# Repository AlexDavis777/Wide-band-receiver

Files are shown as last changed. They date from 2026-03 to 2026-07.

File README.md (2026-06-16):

# Wide band receiver
An all mode wide band receiver project, covering 0.1-860MHz. Using Arduino IDE for firmware, SI4732 as demodulator, AD831 as active mixer and an I2C "tin can" TV tuner for VHF/UHF reception.
A tinySA can be added and will then get synchronized by the receiver via serial connection.      
 
This is an experimental receiver and should not be considered as a flawless building description with guaranteed success. 
It does require RF experience and tools.

It uses single conversion for frequencies below 50MHz and double conversion above. A crystal filter in front of the SI4732 and a SI5351 as local oscillator improve filtering and eliminate chuffing noises. 

A NOS I2C tv tuner covers 50-860MHz. A "shortwave only" version (without tuner) can be compiled.
The driver module "TVTuner.ino" is designed for Philips PAL I2C tuners and has been tested on UR1316-3 and CD1316-3 tuners. UV1316-3 tuner should also work.
These tuners are currently available on the internet from several sources. Tuner AGC voltage gets generated by one of the ESP32 DAC's.   
Other Philips I2C tuners may have a different pinout and different IF and AGC specs, but should work as long as they use the same data format (4 byte Philips telegram).

It may be possible to adapt it for other brands by adjusting the data packet that gets sent to the tuner. 
Philips tuners work fine with +3.3V on the I2C bus. Other brands may need level shifters. NTSC tuners use a different IF and would also require to adapt the LO frequency accordingly.

ESP32, ILI9488 with an RESISTIVE touch display (the red pcb), SI4732, SI5351 and AD831 are the main components. No other displays are supported.
Volume, squelch and fine tune get directly controlled via potentiometers.
Different options like a TCXO version or a hardware narrow band FM demodulator are available.

It does include some nice features, such as remote control over WiFi, digital audio processor, morse decoder, slow scan waterfall, memory bank scanning, station lists, .wav recorder, WIFI file transfer and more.
To build the hardware you should have experience with RF circuits and the appropiate toolset. At least a tinySA and NanoVNA are strongly recommended. 

See the main file SI4732Radio_V0_611.ino for more details.


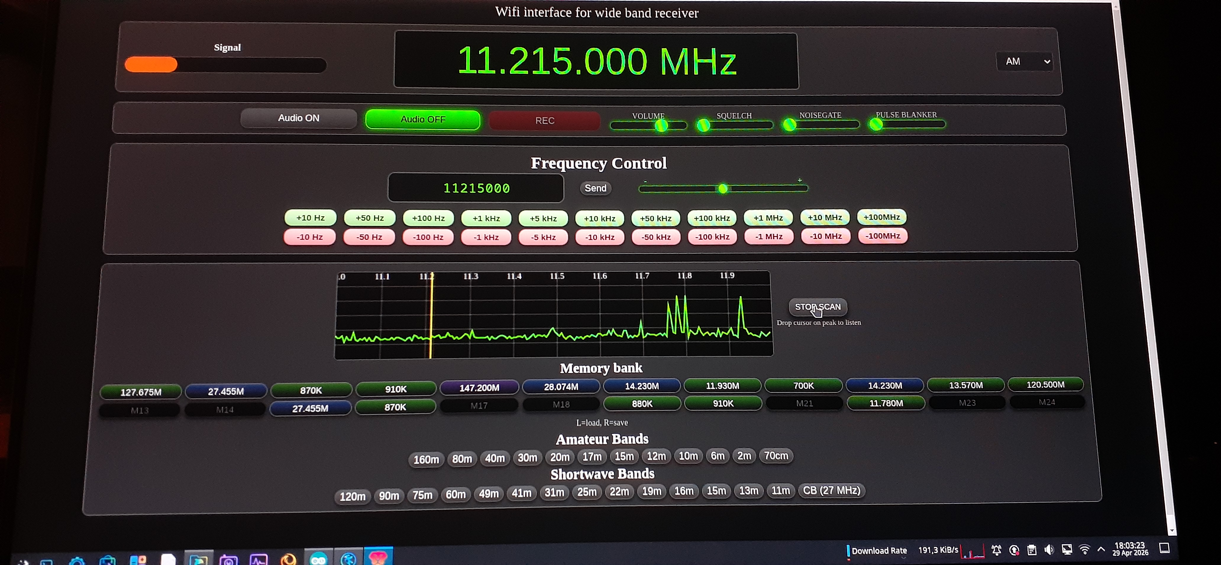
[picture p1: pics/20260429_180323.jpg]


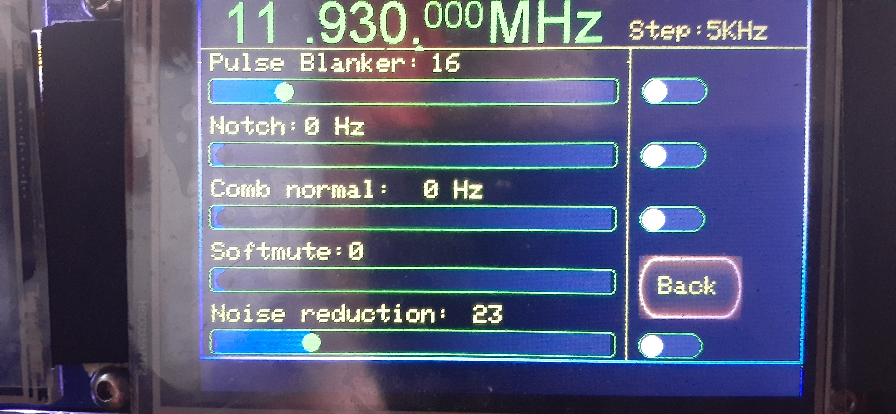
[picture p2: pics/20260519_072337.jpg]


.

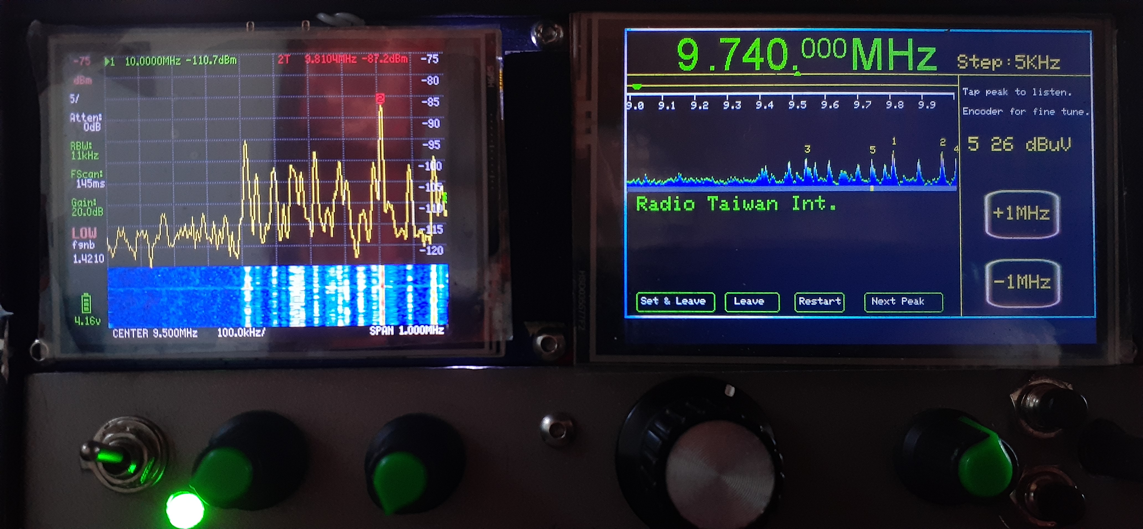
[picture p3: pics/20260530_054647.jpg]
.

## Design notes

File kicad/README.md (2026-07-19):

# Wide band receiver
Added prototype PCBs. Open Source Hardware. Please feel free to use or adapt and improve as you see fit for your project.

Front Bezel and MCU/Display PCB boards work well.
Radio PCB Board works well but is in need of further testing and possible layout optimization.

Rev2 Radio board includes support MAR6-SM on same footprint as SBB5089 and for using ADE-1+ mixer
alternative instead of AD831.
The ADE-1+ mixer does away with a need for the 9 volt regulator and enables powering the radio from 7.4 volts, thus
halving current consumption and reduces regulator heat, making the device more portable.

<p align="center">
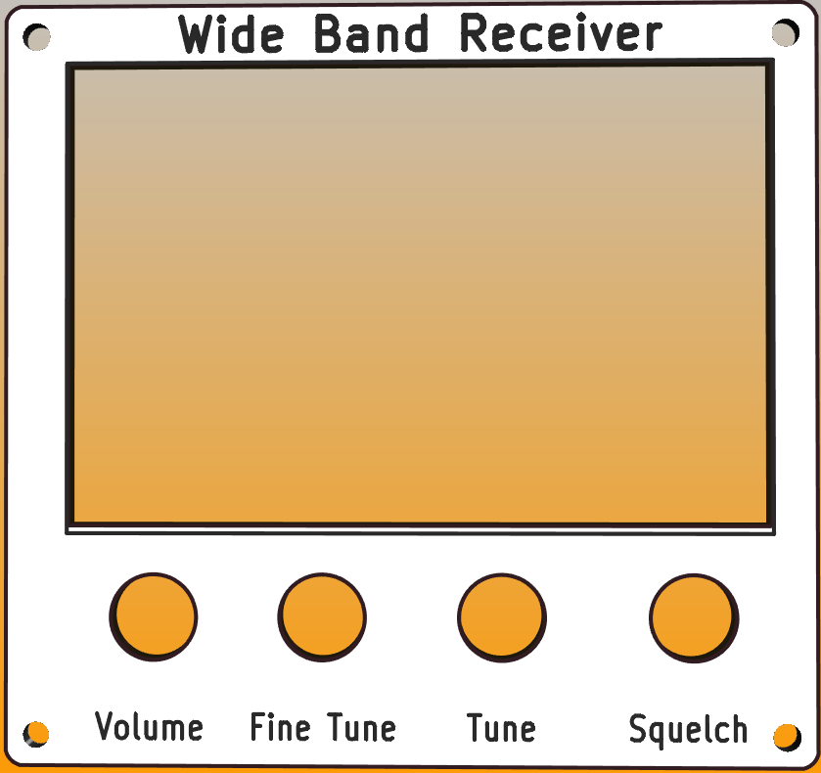
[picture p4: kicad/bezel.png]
    

<p align="center">
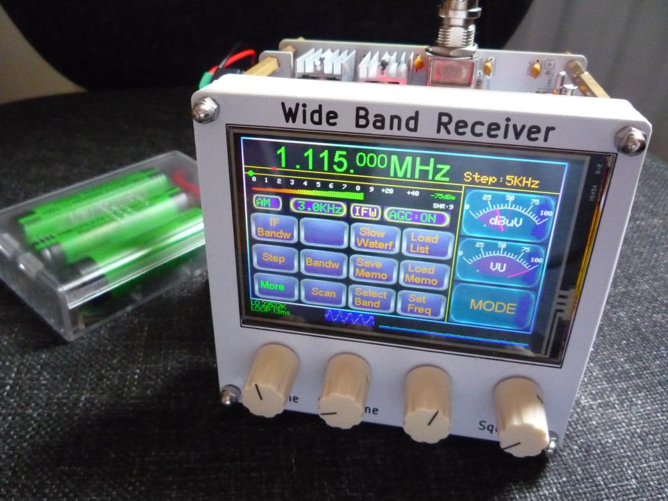
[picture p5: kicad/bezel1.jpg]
    

<p align="center">
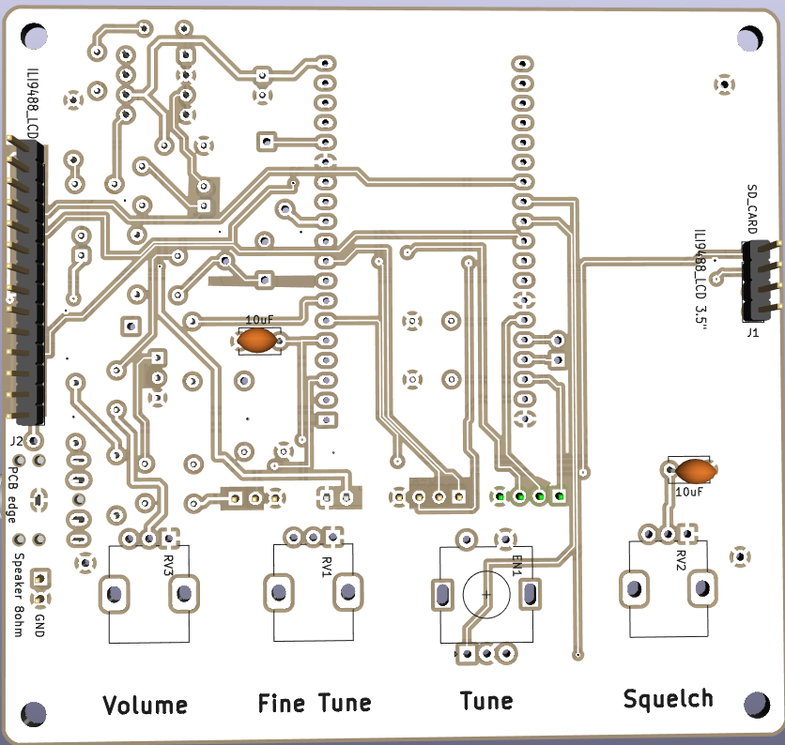
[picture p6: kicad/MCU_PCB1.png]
    

<p align="center">
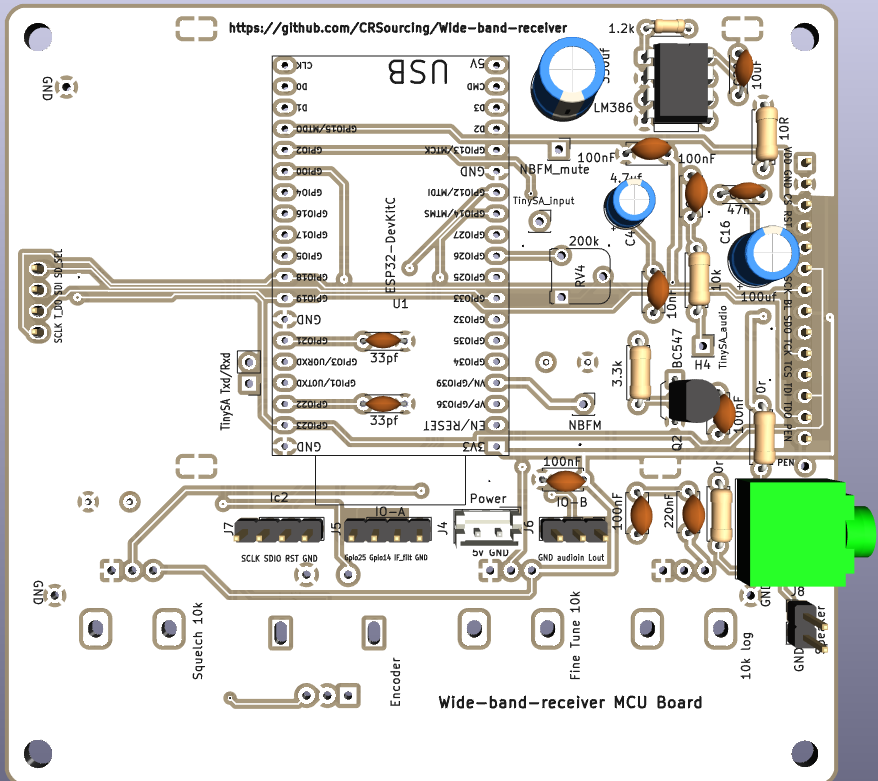
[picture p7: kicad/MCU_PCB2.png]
    

<p align="center">
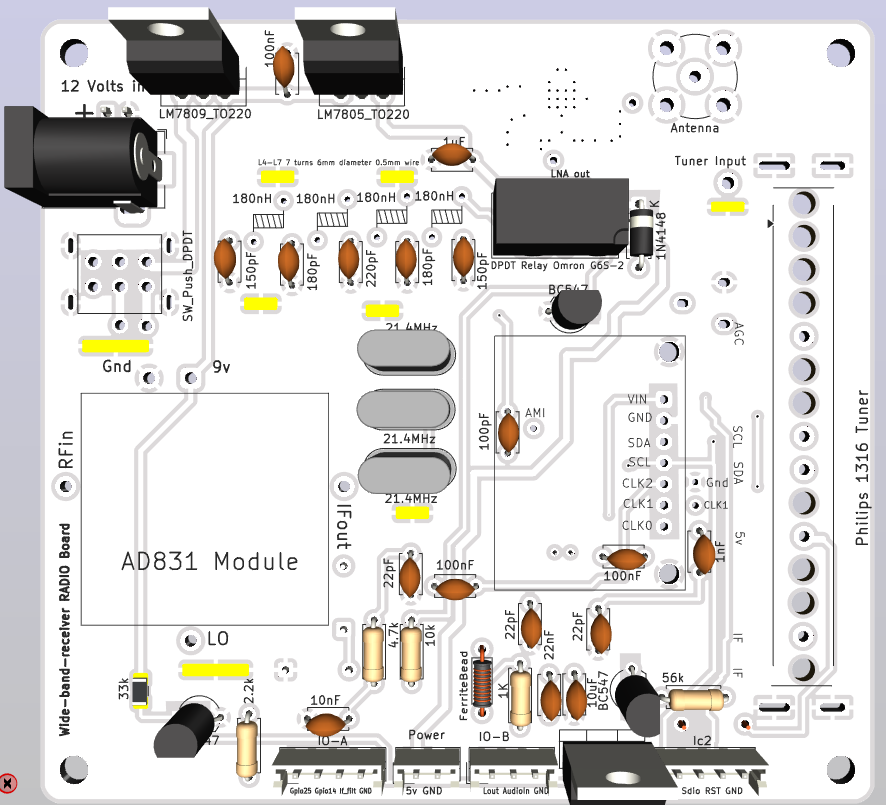
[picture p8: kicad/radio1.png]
    

<p align="center">
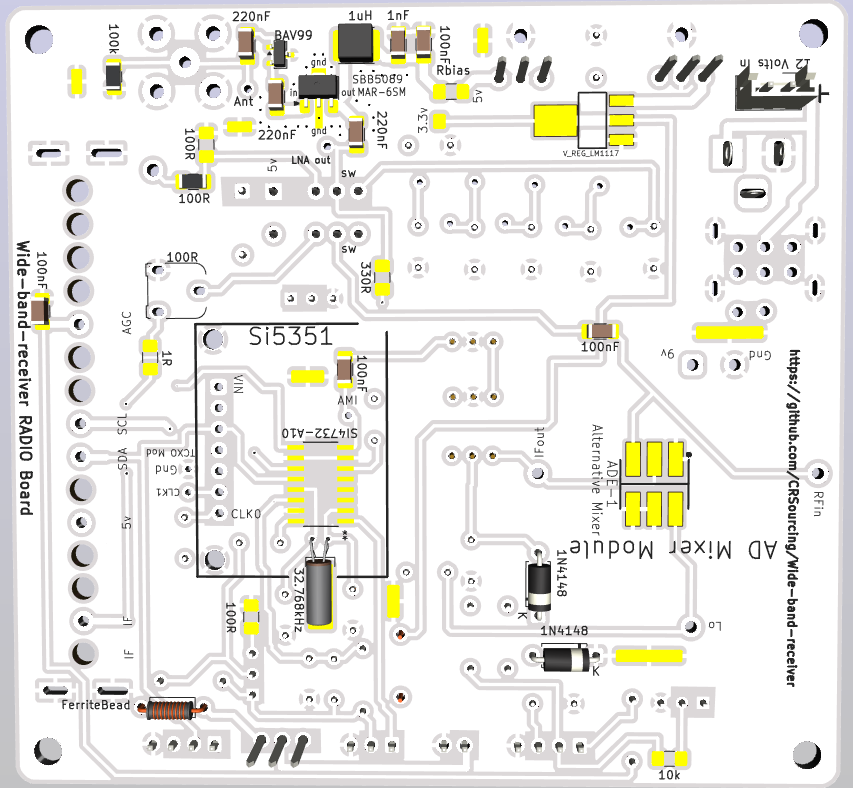
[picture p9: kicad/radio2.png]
    

<p align="center">
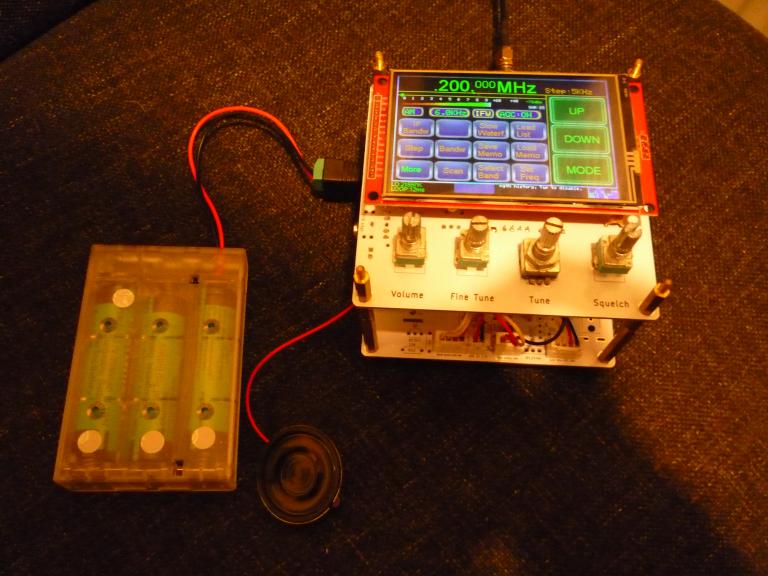
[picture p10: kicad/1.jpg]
    

<p align="center">
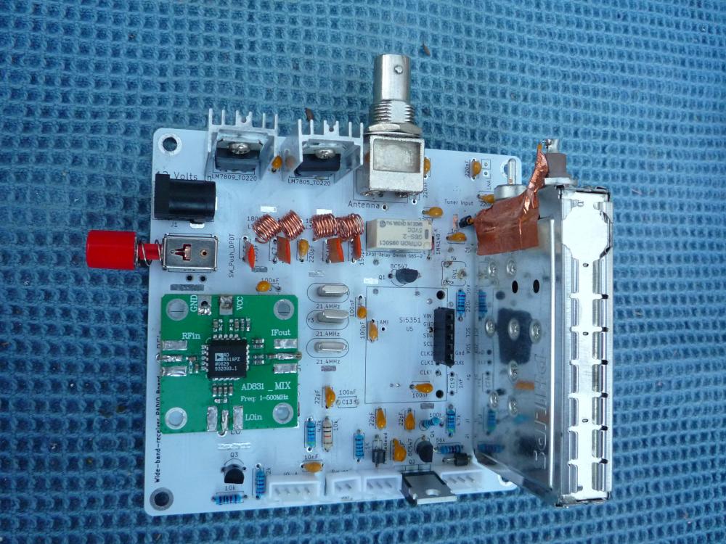
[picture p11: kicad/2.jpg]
    

<p align="center">
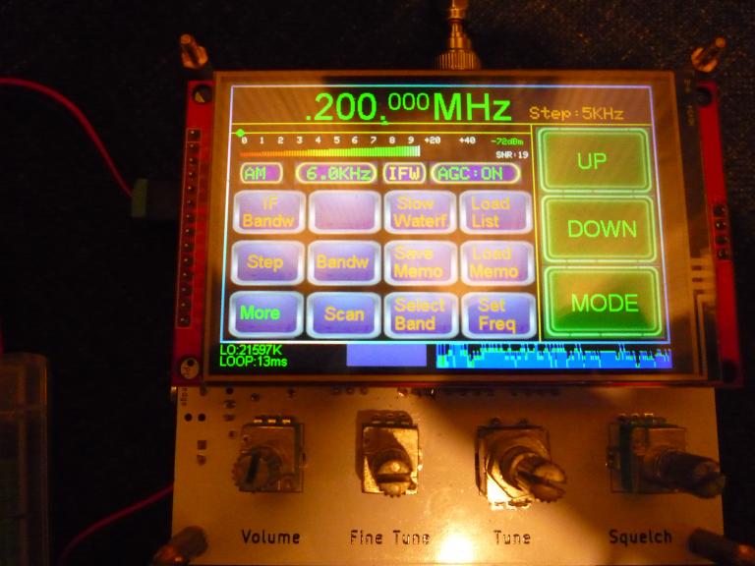
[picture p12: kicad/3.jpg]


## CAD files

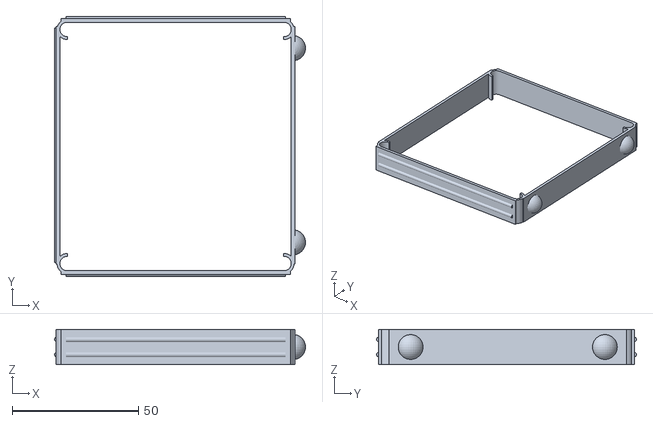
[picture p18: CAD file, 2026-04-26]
3dPrints/Top1.stl
99.5 x 103.0 x 14.0

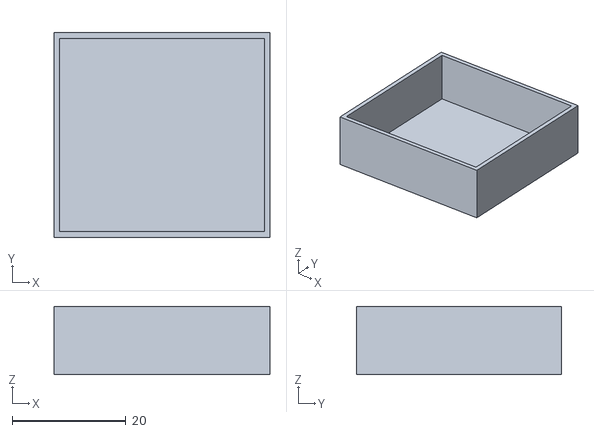
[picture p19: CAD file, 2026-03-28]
3dPrints/screenBox_mixer.stl
38.0 x 36.0 x 12.0

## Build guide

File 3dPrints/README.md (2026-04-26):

# Wide band receiver
3D printed parts added here.

<p align="center">
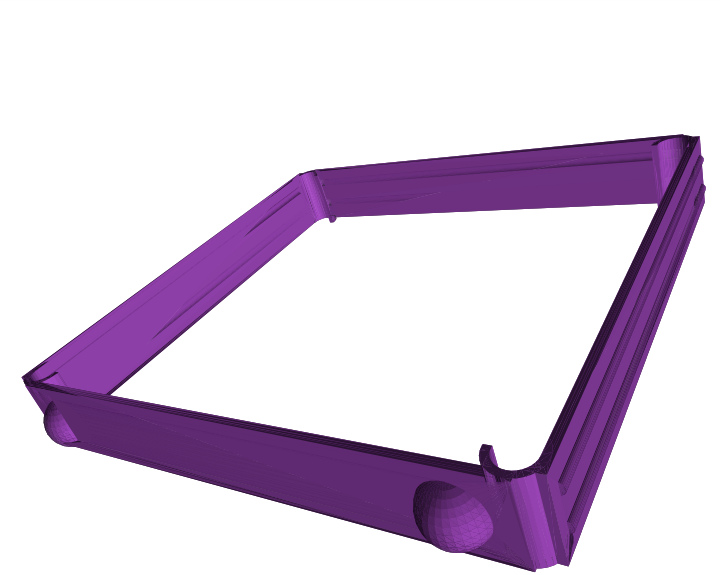
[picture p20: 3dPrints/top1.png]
    

<p align="center">
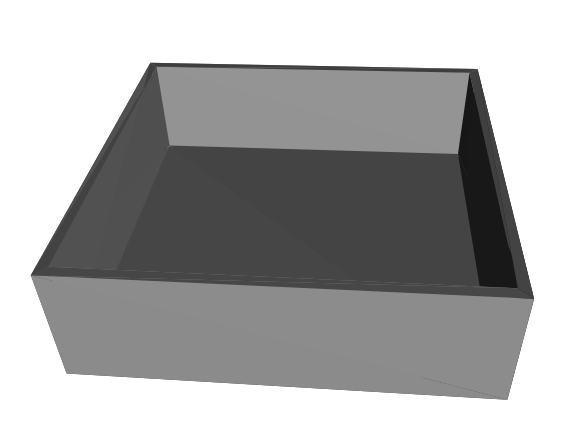
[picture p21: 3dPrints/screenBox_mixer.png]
    

<p align="center">
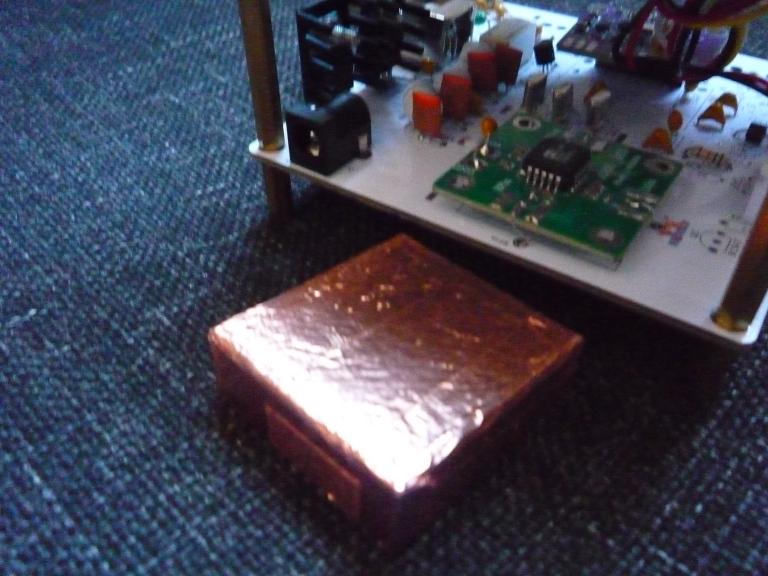
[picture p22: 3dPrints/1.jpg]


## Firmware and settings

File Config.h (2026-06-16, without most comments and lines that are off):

#include <sys/_stdint.h>
#define CONFIG_H
#ifdef TV_TUNER_PRESENT
#define LOW_BAND_LOWER_LIMIT 50000000  // TV tuner bands limits tested with tuner UR1316
#define LOW_BAND_UPPER_LIMIT 167000000
#define MID_BAND_UPPER_LIMIT 454000000
#define HIGH_BAND_UPPER_LIMIT 875000000      // sensitivity decreases rapidly > 850MHz
#define SHORTWAVE_MODE_UPPER_LIMIT 50000000  //above 50MHz tuner is in use
#define HIGHEST_ALLOWED_FREQUENCY HIGH_BAND_UPPER_LIMIT
#else
#define HIGHEST_ALLOWED_FREQUENCY 50000000  // 50MHz
#define SHORTWAVE_MODE_UPPER_LIMIT 50000000
#endif
#define LOWEST_ALLOWED_FREQUENCY 100000  // could go lower, but noise gets dominant
#define TFT_BLACK 0x0000
#define TFT_NAVY 0x000F
#define TFT_DARKDARKGREEN 0x1b41
#define TFT_DARKGREEN 0x03E0
#define TFT_MIDGREEN 0x0584
#define TFT_DARKCYAN 0x03EF
#define TFT_DARKVIOLET 0x2028  // 4,1,8
#define TFT_MAROON 0x7800
#define TFT_PURPLE 0x780F
#define TFT_OLIVE 0x7BE0
#define TFT_LIGHTGREY 0xD69A
#define TFT_DARKGREY 0x7BEF
#define TFT_DARKDARKGREY 0x2945
#define TFT_SILVERBLUE 0x8D5F
#define TFT_BLUE 0x001F
#define TFT_GREEN 0x07E0
#define TFT_CYAN 0x07FF
#define TFT_RED 0xF800
#define TFT_DARKRED 0x90C1
#define TFT_MAGENTA 0xF81F
#define TFT_YELLOW 0xFFE0
#define TFT_WHITE 0xFFFF
#define TFT_ORANGE 0xFDA0
#define TFT_DEEPORANGE 0xf401
#define TFT_GREENYELLOW 0xB7E0
#define TFT_PINK 0xFE19
#define TFT_DARKBROWN 0x6a44
#define TFT_BROWN 0x9A60
#define TFT_LIGHTBROWN 0x9347
#define TFT_GOLD 0xFEA0
#define TFT_SILVER 0xC618
#define TFT_SKYBLUE 0x867D
#define TFT_VIOLET 0x915C
#define TFT_GREY 0x5AEB
#define TFT_FOREGROUND TFT_GOLD
#define TFT_GRID TFT_YELLOW
#define TFT_LIGHTBULB 0xFFDC
#define TFT_BTNBDR TFT_NAVY
#define TFT_BTNCTR TFT_BLUE
#define TFT_MAINBTN_BDR TFT_NAVY
#define TFT_MAINBTN_CTR TFT_GREY
#define TFT_DIAL_BACKGROUND TFT_BLACK
#define TFT_DIAL_TICKS TFT_LIGHTBULB
#define TILE_WIDTH 75
#define TILE_HEIGHT 50
#define SPRITEBTN_WIDTH 80
#define SPRITEBTN_HEIGHT 50
#define M_SIZE 0.59  // meter size, does not affect the sprite frame size
#define DISP_WIDTH 480
#define DISP_HEIGHT 320
#define AM 1
#define LSB 2
#define USB 3
#define NBFM 4
#define WBFM 5
#define SYNC 6  //AM Sync, doesn't work well
#define CW 7
#define FMSTARTFREQ 10000  // WBFM initial freq, use frequency of a nice radio station
#define DEFAULT_AM_STEP 5000
#define DEFAULT_SSB_STEP 1000
#define DEFAULT_CW_STEP 100
#define DEFAULT_SYNC_STEP 5000
#define DEFAULT_NBFM_STEP 12500
#define DEFAULT_WBFM_STEP 100000
#define IF_FILTER_BANDWIDTH_PIN 0  // switches filter bandwidth, GPIO 0 okay for this
#define RESET_PIN 12               // SI4735 reset
#define NBFM_MUTE_PIN 13           // Hardware NBFM demodulator mute pin, muted when another modType is in use
#define RELAY_SWITCH_OUTPUT 14     // activates IF  and LNA relays. Low = tvTuner connected to LNA and AD831
#define ENCODER_PIN_B 16           // Encoder left and right pins
#define ENCODER_PIN_A 17           // Encoder left and right pins
#define ESP32__SDA 21           //  bus
#define ESP32__SCL 22           //  bus
#define TUNER_AGC_PIN 25           // tuner AGC pin
#ifdef NBFM_DEMODULATOR_PRESENT
#define TUNING_VOLTAGE_READ_PIN 27  // Tuning voltage read pin
#endif
#define ENCODER_BUTTON 33   // encoder pressbutton pin
#define MUTEPIN 32          // goes via 3.3K to base of external mute transistor
#define FINETUNE_PIN 34     // finetune pot center pin
#define SQUELCH_POT 35      // squelch pot center pin
#define AUDIO_INPUT_PIN 36  // audio input for FFT analysis from SI4732
#define PULSE_PIN 39        // squarewave audio input
#define WATERFALL_SCREEN_WIDTH 480
#define WATERFALL_SCREEN_HEIGHT 220
#define FRAMEBUFFER_240 240
#define FRAMEBUFFER_HEIGHT 220
#define AUDIO_FRAMEBUFFER_HEIGHT 40
#define TIME_UNTIL_ANIMATIONS 60  // seconds until animations start (pacm, audio waterfall)
#define TFT_SCK 18
#define TFT_MOSI 23
#define TFT_MISO 19
#define TFT_RESET 4
#define FORMAT_LittleFS_IF_FAILED true  //format the LittleFS if not already formatted or error
#define SCK 18    // definitions for SD card
#define MISO 19   //MISO=SDO
#define MOSI 23   //MOSI=SDI
#define SD_CS 33  // Connect CS to GPIO33 (also used for encoder press button), all other connections in parallel to SPI bus.
#define SAMPLES 256
#define FFT_SPEED_OVER_PRECISION
#define FFT_SQRT_APPROXIMATION
#define DEFAULT_SPAN 1000000  // cover 1MHz
#define FREQ_TO_MHZ FREQ / 1000000 * 1000000
#define FREQ_TO_KHZ FREQ / 1000
#define WINDOW_CENTER_FREQ (FREQ / 1000000 * 1000000) + (DEFAULT_SPAN / 2)
#define SHOW_SPLASHSCREEN
Rotary encoder = Rotary(ENCODER_PIN_A, ENCODER_PIN_B);
TFT_eSPI tft = TFT_eSPI();
TFT_eSPI_ext etft = TFT_eSPI_ext(&tft);  // Install from https://github.com/FrankBoesing/TFT_eSPI_ext // Fonts avail. in the following sizes:
TFT_eSprite spr1 = TFT_eSprite(&tft);  // miniwindow, bottom center of screen
TFT_eSprite spr2 = TFT_eSprite(&tft);  // rolling RSSI indicator
TFT_eSprite spr3 = TFT_eSprite(&tft);  // audio waterfall after user inactivity
Si5351 si5351(0x60);  //Si5351  Address 0x60
SI4735 si4735;
Preferences preferences;  // Flash save data
PNG png;
File myfile;
SdFat sd;  // SdFat library
FsFile f;
SPIClass spiSD = SPIClass(VSPI);                // for SDcard
DacESP32 dac2(GPIO_NUM_26), dac1(GPIO_NUM_25);  // dac2 for sine wave oscillator, dac1 for tuner AGC or SW RF attenuator
float RvReal[SAMPLES * 2];
float RvImag[SAMPLES * 2];
ArduinoFFT<float> FFT = ArduinoFFT<float>(RvReal, RvImag, 512, 8000);  // 4KHz max, 255 usable bins
RingBuffer logBuffer;                                                  // debug logs
WebServer server(80);                // LittleFS uploader
AsyncWebServer aserver(HTTTP_PORT);  // WiFi interface
AsyncWebSocket ws("/ws");            // websocket
const uint16_t size_content = sizeof ssb_patch_content;  // see ssb_patch_content in patch_full.h or patch_init.h
volatile bool clw = false;                               // encoder direction clockwise
volatile bool cclw = false;                              // counter clockwise
const char ver[] = "V.611";  // version
long I2C_BUSSPEED = 500000;  // Adjust as needed.
long STEP;                    //STEP size
long OLDSTEP;
const long MIN_FREQ = 100000;          // lowest frequency
long SI5351calib = 0;                  //  si5351.set_correction
long fineTuneOffset = 0;               // used when fine tune offset will not get displayed
long passbandShift = 0;                // shift SI4732 frequency through filter passband
const long tunerIFLowEnd = 37000000l;  // Defines the 1 MHz segment of the tuner IF spectrum which will be used. This constant determines the low end of the segment.
long FREQ = 100000;            // receiver tuned frequency
long FREQ_OLD = -1;            // start with != FREQ value
long F_OLD = -1;               // value holder for displayLOFreq()
long LO_RX;                    // SI5351 frequency in Hz
int SI4735TUNED_FREQ = 21400;  // 1st IF in KHz Also mid frequency of crystal filter, SI4732 needs to be tuned to it.
bool wideIFFilter = true;  // IF filter bandwidth false = narrow, true = wide;
bool afcEnable = false;
int NBFMOffset = 0;              // shift of  SI4735TUNED_FREQ in KHz to demodulate FM on the flank of the filter.
int afcVoltage = 410;            // voltage tap from the quadrature demodulator
int discriminatorZero;           // middle of the tuning meter needle
uint8_t tuningMeterDivider = 5;  // adjust so that the tuning meter shows deviation in KHz correctly
uint8_t triggerUpdate = 0;       // triggers AGC updates (Attn buttons)
int8_t SWGainCorrection = 10;    //  corrects shortwave S Meter
uint16_t SWAttn = 0;             // Shortwave attenuator attenuation, 0 = 0dB, 255= 30dB attenuation
uint8_t SWMinAttn = 0;           // Shortwave attenuator minimum attenuation, 0 = 0dB, 255= 30dB attenuation
long lastAMFREQ = -1;            // AM frequency before switching to WBFM
long span = 1000000;             // tinySA default span, configured in TSA Presets 0 and 1
long potVal;                     // fine tune potentiometer read value
long lim2 = 0;                   // frequency limits from touchpad entries
long lim1 = 0;                   // frequency limits from touchpad entries
long keyVal = 0;                 // scan mode frequencies delivered from touchpad
bool TVTunerActive = false;     //will get set to true when tuner in use
bool lowSideInjection = false;  // for debugging, this will change injection mode
uint8_t gainLimit = 180;        // adjust tuner gain when no signal received, depending on gain of the LNA. Must be as low as possible to reduce cross modulation
uint8_t agcVal = gainLimit;     // starting point of the AGC
uint32_t OLDPLLFREQ = -1;
uint32_t PLLFREQ = 0;              // PLL freq of the TV tuner
int16_t tunerOffsetPPM = 0;        // corrects tuner crystal offset
int8_t tunerGainCorrection = -10;  // corrects sMeter and dBm values when tuner is in use
#ifdef TV_TUNER_PRESENT
long MAX_FREQ = HIGHEST_ALLOWED_FREQUENCY;
#endif
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

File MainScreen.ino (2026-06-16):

void mainScreen() {  // main screen does not block loop(), all other screens do

  if (redrawMainScreen) {  // redraw main screen when coming from a function that overwrites it
    resetSmeter = true;
    F_OLD = -1;  // re trigger LO display
    drawBigBtns();
    drawMainButtons();
    DrawSmeterScale();
    printModulation();
    printBandWidth();
    showIFBandwidth();
    printAGC();
    readSquelchPot(true);  // read and draw position
    redrawMainScreen = false;
  }
  readMainBtns();
}


//##########################################################################################################################//
void redrawIndicators() {

  tft.fillRect(3, 52, 336, 30, TFT_BLACK);  // overwrite area for spectrum
  tft.fillRect(3, 82, 336, 41, TFT_BLACK);  // overwrite area for waterfall
  F_OLD = -1;                               // re trigger LO display
  DrawSmeterScale();
  printModulation();
  printBandWidth();
  showIFBandwidth();
  printAGC();
  redrawMainScreen = true;  // this forces readSquelchPot() to redraw the squelch line and circle
  readSquelchPot(true);
  redrawMainScreen = false;
}


//##########################################################################################################################//

void drawMainButtons() {

  // Background
  if (!altStyle)
    tft.fillRect(2, 56, 337, 233, TFT_BLACK);
  else
    drawButton(2, 56, 337, 233, TFT_NAVY, TFT_DARKGREY);

  draw12Buttons(TFT_BTNCTR, TFT_BTNBDR);

  struct Button {
    const int x;
    const int y;
    const char *label;
  };

  const Button buttons[] PROGMEM = {
    { 275, 245, "Set" }, { 185, 245, "Select" }, { 110, 255, "Scan" }, { 100, 198, "Bandw" }, { 25, 198, "Step" }, { 185, 188, "Save" }, { 270, 188, "Load" }, { 188, 132, "Slow" }, { 270, 132, "Load" }, { 185, 265, "Band" }, { 275, 265, "Freq" }, { 185, 208, "Memo" }, { 267, 208, "Memo" }, { 185, 152, "Waterf." }, { 270, 152, "List" }
  };

  etft.setTTFFont(Arial_14);
  for (int i = 0; i < sizeof(buttons) / sizeof(buttons[0]); i++) {
    etft.setCursor(buttons[i].x, buttons[i].y);
    etft.setTextColor(textColor);
    if (i == 2 && scanMode)
      etft.setTextColor(TFT_SKYBLUE);
    etft.print(buttons[i].label);
  }

  // "More" button
  drawButton(8, 234, TILE_WIDTH, TILE_HEIGHT, TFT_MIDGREEN, TFT_DARKGREEN);
  etft.setTextColor(TFT_GREEN);
  etft.setCursor(20, 254);
  etft.print(F("More"));
  etft.setTextColor(textColor);

#ifdef TINYSA_PRESENT
  etft.setCursor(15, 132);
  etft.print(F("TinySA"));
  etft.setCursor(14, 152);
  etft.print(F("Config"));

#else
  etft.setCursor(40, 132);
  etft.print(F("IF"));
  etft.setCursor(18, 152);
  etft.print(F("Bandw"));
#endif

#ifdef TV_TUNER_PRESENT
  etft.setCursor(100, 132);
  if (TVTunerActive) {
    etft.setTextColor(TFT_SKYBLUE);
    etft.print(F("Tun."));
    etft.setCursor(100, 152);
    etft.print(F("Attn."));
  }
#endif

  if (!TVTunerActive) {
#ifdef SW_ATTENUATOR_PRESENT
    etft.setTextColor(TFT_GREEN);
    etft.print(F("SW"));
    etft.setCursor(100, 152);
    etft.print(F("Attn."));
    etft.setTextColor(textColor);
#endif
  }
}


//##########################################################################################################################//

void readMainBtns() {



  if (!pressed)
    return;



  int buttonID = getButtonID();
  if (!buttonID)
    return;  // outside of area


  redrawMainScreen = true;
  tft.fillRect(135, 295, 92, 25, TFT_BLACK);  // overwrite frozen spectrum window
  switch (buttonID) {
    case 21:
#ifdef TINYSA_PRESENT
      tinySAScreen();
#else
      wideIFFilter = !wideIFFilter;
      setIFBandwidth();
      showIFBandwidth();
#endif
      tRel();
      return;
    case 22:
      hideBigBtns();
#ifdef TV_TUNER_PRESENT
      if (TVTunerActive)
        setInitialTunerGain();
#endif

#ifdef SW_ATTENUATOR_PRESENT
      if (!TVTunerActive)
        setRFAttenuatorMinAttn();
#endif

      break;
    case 23:
      selectWaterFall();
      tRel();
      break;
    case 24:
      picoMenu();
      rebuildMainScreen(false);
      FREQ_OLD = -1;  // trigger update
      return;
    case 31:
      hideBigBtns();
      setSTEP();  // use touchbuttons
      break;
    case 32:
      hideBigBtns();
      setBandwidth(0);  // use touchbuttons
      tRel();
      break;
    case 33:
      hideBigBtns();
      showMemo(false, 1);
      writeMemo();
      tRel();
      break;
    case 34:
      hideBigBtns();
      showMemo(true, 1);
      readMemo();
      tft.fillRect(0, 294, 374, 25, TFT_BLACK);  // overwrite remanents of station names
      displayDebugInfo = true;                   // restore debug info
      tRel();
      break;
    case 41:
      FREQ_OLD = -1;  // re trigger LO display
      hideBigBtns();
      SecScreen();
      tRel();
      break;
    case 42:
      ScanMode();
      tRel();
      tx = ty = pressed = 0;
      break;
    case 43:
      hideBigBtns();
      setBand(false);  // Select Band
      tRel();
      break;
    case 44:
      hideBigBtns();
      freqScreen();
      break;
    default:
      tx = ty = pressed = 0;
      tRel();
      return;
  }
}



//##########################################################################################################################//

void setBandwidth(int mode) {  // mode 0 = bandwidth selected from menu. mode -1 and 1 are called  by touching the indicator areas
  const int TEXT_Y = 195;
  const int positions[] = { 24, 106, 191, 272 };

  const uint8_t usbLsbBandWidths[] = { 0, 1, 2, 3 };
  const uint8_t amBandWidths[] = { 3, 2, 1, 0 };
  const uint8_t cwBandWidths[] = { 4, 5, 3, 3 };

  const char *amBandwidth[] = { "2KHz", "3KHz", "4KHz", "6KHz" };
  const char *ssbBandwidth[] = { "1.2KHz", "2.2KHz", "3KHz", "4KHz" };
  const char *cwBandwidth[] = { "0.5KHz", "1.0KHz", "", "" };
  const char **bandwidth = nullptr;



  if (modType == WBFM)
    return;


  if (mode == 0) {
    for (int j = 0; j < 4; j++) {
      drawButton(8 + j * 83, 235, TILE_WIDTH, TILE_HEIGHT, TFT_BTNCTR, TFT_BTNBDR);
      drawButton(8 + j * 83, 178, TILE_WIDTH, TILE_HEIGHT, TFT_BTNCTR, TFT_BTNBDR);
    }

    tft.fillRect(3, 119, 334, 58, TFT_BLACK);  // overwrite highest row

    etft.setTTFFont(Arial_14);
    etft.setTextColor(TFT_GREEN);

    if (modType == AM)
      bandwidth = amBandwidth;
    else if (modType == USB || modType == LSB || modType == SYNC)
      bandwidth = ssbBandwidth;
    else if (modType == CW)
      bandwidth = cwBandwidth;


    if (bandwidth != nullptr) {
      for (int i = 0; i < 4; ++i) {

        if (modType == AM)
          etft.setCursor(positions[i], TEXT_Y);
        if (modType == LSB || modType == USB || modType == SYNC || modType == CW)
          etft.setCursor(positions[i] - 10, TEXT_Y);  // text is wider

        etft.print(bandwidth[i]);
      }
      etft.setTextColor(textColor);  // Reset to default text color
    }


    tDoublePress();

    delay(10);
    getButtonID();

    if (row == 3) {

      if (modType == USB || modType == LSB || modType == SYNC) {
        bandWidth = usbLsbBandWidths[column - 1];
        lastSSBBandwidth = bandWidth;
      } else if (modType == AM) {
        bandWidth = amBandWidths[column - 1];
        lastAMBandwidth = bandWidth;
      } else if (modType == CW) {
        bandWidth = cwBandWidths[column - 1];
        lastSSBBandwidth = bandWidth;
      }
    }

  }  // endif mode == 0


  else {  // mode -1 and mode 1 are used when touching the indicator area on the left or right

    const uint8_t *bandWidths;
    int maxIndex = 3;
    int i = 0;
    bool isIncrement = (mode == 1);

    if (modType == AM) {
      bandWidths = amBandWidths;
    } else if (modType == USB || modType == LSB || modType == SYNC) {
      bandWidths = usbLsbBandWidths;
    } else if (modType == CW) {
      bandWidths = cwBandWidths;
      maxIndex = 1;
    } else {
      return;
    }

    // find index
    while (i < maxIndex && bandWidths[i] != bandWidth) {
      i++;
    }

    // modify index
    if (isIncrement && i < maxIndex) {
      i++;
    } else if (!isIncrement && i > 0) {
      i--;
    }

    // update bandwidth
    bandWidth = bandWidths[i];
  }
  // set bandwidth
  if (modType == LSB || modType == USB || modType == SYNC || modType == CW) {
    si4735.setSSBAudioBandwidth(bandWidth);
    if (bandWidth <= 2) {
      si4735.setSBBSidebandCutoffFilter(0);
    } else {
      si4735.setSBBSidebandCutoffFilter(1);
    }
  }

  if (modType == AM) {
    si4735.setBandwidth(bandWidth, 1);
  }
  printBandWidth();
}

//##########################################################################################################################//

void printBandWidth() {

  if (altStyle)
    tft.fillRoundRect(75, 95, 92, 22, 10, TFT_BLUE);

  else {
    tft.pushImage(75, 92, 92, 26, (uint16_t *)Oval92);
  }

  tft.setTextColor(TFT_GREEN);
  tft.setCursor(77, 98);

  switch (modType) {
    case WBFM:
      tft.print(F(" 300KHz"));
      break;
    case NBFM:
      tft.print(F(" 10KHz"));
      break;
    case CW:
      if (bandWidth == 4)
        tft.print(F(" 0.5KHz"));
      if (bandWidth == 5)
        tft.print(F(" 1.0KHz"));
      break;
    case USB:
    case LSB:
    case SYNC:
      tft.print(bandWidth == 0 ? " 1.2KHz" : bandWidth == 1 ? " 2.2KHz"
                                           : bandWidth == 3 ? " 4.0KHz"
                                                            : " 3.0KHz");
      break;
    case AM:
      tft.print(bandWidth == 0 ? " 6.0KHz" : bandWidth == 1 ? " 4.0KHz"
                                           : bandWidth == 2 ? " 3.0KHz"
                                                            : " 2.0KHz");
      break;
  }
}
//##########################################################################################################################//


void showIFBandwidth() {


  if (altStyle)
    tft.fillRoundRect(174, 95, 45, 22, 10, TFT_BLUE);

  else
    tft.pushImage(170, 92, 55, 26, (uint16_t *)Oval55);


  tft.setTextColor(TFT_GREEN);
  tft.setCursor(179, 98);

  if (wideIFFilter) {
    tft.setTextColor(TFT_YELLOW);
    tft.print(F("IFW"));
  } else {
    tft.setTextColor(TFT_GREEN);
    tft.print(F("IFN"));
  }

  tft.setTextColor(textColor);
}


//##########################################################################################################################//

void ScanMode() {

  scanMode = !scanMode;
}

//##########################################################################################################################//


int getButtonID(void) {


  // y 1st row buttons : 121 - 171
  // y 2nd row buttons : 178 - 228
  // y 3rd row buttons : 235 - 285
  // vTouchSpacing = 68
  // buttonHeight = 50;



  column = 1 + (tx / HorSpacing);  // get row and column
  row = 1 + ((ty - 35) / vTouchSpacing);


  if (row > 4 || column > 4 || ty > 293 || ty < 121)  // outside area
    return 0;
  else
    return row * 10 + column;
}

//##########################################################################################################################//

void setIFBandwidth() {

  if (wideIFFilter)
    digitalWrite(IF_FILTER_BANDWIDTH_PIN, HIGH);
  else
    digitalWrite(IF_FILTER_BANDWIDTH_PIN, LOW);

    preferences.putBool("bwf", wideIFFilter);
  Serial.printf("Wide IF Filter: %s\n", wideIFFilter ? "Yes" : "No");
}


//###############################################################################################//

void pacM(bool jumpBack) {
  static bool openMouth = false;
  static bool movRight = true;
  static bool movingDown = true;
  const int movHor = 5;
  const int movVer = 15;
  static int xPos = 5;
  const int yPosStart = 85;
  const int yPosEnd = 275;
  static int yPos = yPosStart;
  const int spriteSize = 24;

  drawRandomObjects();

  // Clear prev pos
  tft.fillRect(xPos, yPos, spriteSize, spriteSize, TFT_BLACK);

  // Update pos
  xPos += movRight ? movHor : -movHor;

  // Draw sprite
  if (openMouth) {
    tft.pushImage(xPos, yPos, spriteSize, spriteSize,
                  movRight ? pr : pl);

    if (random(200) == 1 && !movRight && xPos < 280) {  // green gas
      tft.pushImage(xPos + 20, yPos + 10, 20, 10, grS);
      delay(100);
      tft.pushImage(xPos, yPos, spriteSize, spriteSize,
                    pcRed);
      delay(1000);
      tft.fillRect(xPos, yPos, spriteSize, spriteSize, TFT_BLACK);
      if (xPos >= 5 + 2 * movHor)
        xPos -= 2 * movHor;
    }

  }

  else {
    tft.pushImage(xPos, yPos, spriteSize, spriteSize,
                  movRight ? prc : plc);
  }

  openMouth = !openMouth;

  if (jumpBack && get_Touch()) {
    tx = ty = pressed = 0;
    tRel();
  }

  // Boundary check
  if (xPos >= 312 || xPos <= 5) {
    tft.fillRect(xPos, yPos, spriteSize, spriteSize, TFT_BLACK);
    movRight = !movRight;

    // Update vertical pos
    if (movingDown) {
      yPos += movVer;
    } else {
      yPos -= movVer;
    }

    // check direction limits
    if (yPos > yPosEnd) {
      movingDown = false;
      yPos -= movVer;
    } else if (yPos <= yPosStart) {
      movingDown = true;
      yPos += movVer;
    }
  }
}
//###############################################################################################//
void drawRandomObjects() {

  if (!funEnabled)
    return;

  const int yPosStart = 95;
  const int yShift = 24;

  if (1 == random(600))
    tft.pushImage(5 + random(290), yPosStart + random(6) * yShift, 30, 30, apple);
  if (1 == random(600))
    tft.pushImage(5 + random(290), yPosStart + random(6) * yShift, 30, 30, cherry);
  if (1 == random(600))
    tft.pushImage(5 + random(290), yPosStart + random(6) * yShift, 30, 30, strawberry);
  if (1 == random(600))
    tft.pushImage(5 + random(290), yPosStart + random(6) * yShift, 40, 30, radio);
  if (1 == random(600))
    tft.pushImage(5 + random(290), yPosStart + random(6) * yShift, 30, 40, dino);
  if (1 == random(600))
    tft.pushImage(5 + random(290), yPosStart + random(6) * yShift, 20, 30, mush);
  if (1 == random(600))
    tft.pushImage(5 + random(290), yPosStart + random(6) * yShift, 40, 30, cam);
}

//###############################################################################################//
void resetMainScreen(void) {

  redrawMainScreen = true;
  tx = ty = pressed = 0;
}
//###############################################################################################//

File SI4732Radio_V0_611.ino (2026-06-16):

//##########################################################################################################################//

//***************** Please note that this firmware will NOT work on ATS25 derivates! ***********************************//


//IMPORTANT: To compile, select the "ESP32 Dev Module" and the "No OTA (2MB APP, 2MB SPIFFS)" partition scheme.

// Comment/uncomment compiler directives according to your hardware:

#define TV_TUNER_PRESENT  // If this option is commented out, a shortwave receiver version will compile. In this case max. FREQ = 50MHz.

//#define AUDIO_SQUAREWAVE_PRESENT  // Audio squarewave present on GPIO39 for SSTV and RTTY decoding. Experimental.

#define FAST_TOUCH_HANDLER  // Invokes a faster touch handler with reduced sampling. Could cause spurious errors if the touchscreen is worn out, but increases speed significantly. No problems so far.

#define SHOW_DEBUG_UTILITIES  // Will show Debug utilities panel. Contains helper functions and status messages.

//#define NBFM_DEMODULATOR_PRESENT  // Uses an additional MC3361 as hardware NBFM demodulator. Better audio than the SI4732 flank demodulator. Provides a "tuning" meter like in old FM Stereo receivers and software AFC.

//#define CRYSTAL_FREQ_BELOW_IF  // Activate only if using an NBFM demdulator with a crystal frequency below 21.4MHz. Activating will reverse afc and tuning meter direction.

#define SI5351_GENERATES_CLOCKS  //If active, the SI5351 will generate the LO frequency plus 2 clocks, 4MHz for the tuner and 32768Hz for the SI4732.

//#define TINYSA_PRESENT  // Syncs and controls a tinySA with receiving frequency, if connected via serial to the ESP32.

//#define SW_ATTENUATOR_PRESENT  // Activate only if a voltage controlled attenuator is present in the shortwave RF path. Generates gain control voltage on dac1(GPIO_NUM_25). 0V = max. gain, 3.3V = min gain.

#define HTTTP_PORT 80  // Port for remote interface. Change if you connect from outside your local WiFi.

//#define FLIP_IMAGE  // Activate this if the image is upside down.

//#define TFT_INVERSION_ON  // Activate if the image is inverted.


//##########################################################################################################################//

/*
This firmware covers a wide band receiver project. It is an experimental receiver and should not be considered as a flawless building description with guaranteed success. 
It does require RF experience and tools.

It uses a NOS "tin can" I2C TV tuner and covers 0.1 - 860MHz.
The driver module "TVTuner.ino" is designed for Philips PAL I2C tuners and has been tested on CD1316-3  and on UR1316-3 tuners. UV1316-3 tuner should also work.
Other Philips I2C tuners may have a different pinout and different IF and AGC specs, but many use the same data format and should work.

It may be possible to adapt it for other brands by adjusting the data packet that gets sent to the tuner. 
Philips tuners work fine with +3.3V on the I2C bus. Other brands may need level shifters.


It uses ESP32, ILI9488 with an RESISTIVE touch display (the red pcb), SI4732, SI5351 and AD831 as main components. No other displays are supported.
It uses potentiometers for volume, squelch and fine tune.
A tinySA can be used as optional panorama adapter and will then get automatically configured and updated by the firmware. 
The code is a bit rough since I am not a programmer. It does include some nice features though, such as morse decoder, slow scan waterfall, memory bank scanning, web tools, etc.
To build the hardware you should have experience with RF circuits and the appropiate toolset. At least a tinySA and NanoVNA are strongly recommended. 
At least basic Arduino programming knowledge helps a lot!


Optionally, the code can be compiled for a shortwave receiver only version. In this case you will have a receiver that covers 0-50MHz.
The shortwave receiver will have better filtering and smoother tuning than a SI4732 only receiver.
If you build the"shortwave only" version, please connect the ouput of the lowpass via 220nF to the RF input of the AD831 mixer.

For testing, the GUI can be started with only the ESP32 and the ILI9488 display connected, but responses will be sluggish and several of the functions will not work.
As a next step, the receiver can be tested with the SI4732 connected (no SSB). Therefore select "No Mixer" in the "Debug" panel. 
In this case connect the antenna directly to the AM input of the SI4732. "No Mixer" is not sticky and for testing only.


IMPORTANT: To compile, select the "ESP32 Dev Module" and the "No OTA (2MB APP, 2MB SPIFFS)" partition scheme. 
It should then compile without issues. Some warning messages from the libraries may show up. They are not relevant. 
Latest Arduino IDE version and library versions will work. Older versions may break the code. 


Hardware description:

1. RF gets amplified 19 db using a SBB5089 gain block. SBA4089, YG602020 or any other gain block that goes down to 100KHz with a high enough IP3 can also be used. 

A small signal relay switches a lowpass filter btw. antenna and gain block when in SW mode. This relay and lowpass can be omitted, but strong FM radio stations could then saturate the gain block.
Another small signal relay switch the LNA output between the tuner input (75Ohms) and the second 50MHz lowpass filter. It also switches the tuner IF output 
Schematic for an optional frontend has been included. The optional frontend uses RF switch IC's instead of relays. It is harder to build, but avoids the disadvantages of the relays. 


The TV tuner pins  are connected to the small signal relay, the I2C bus and the AGC output of the ESP32. 
A transistor logic switches the tuner and the boost converter power off when frequency < 50MHz.
The UV1316 tuner has a different pinout and will need a 5-> 33V boost converter 

The ACG voltage from the ESP32 drives tuner gain down when a  strong signal is received. 
To reduce intermodulation, the AGC voltage reduces tuner amplifiction even when no signal is received.


2. The IF output of the tuner connects via a trimpot to the lowpass filter. Adjust the trimpot to the lowest signal level that causes no SNR degradation. 
The second lowpass filter should have at least 70dB attenuation in the FM radio band and above.
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

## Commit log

2026-03-25 Add prototype PCB's
2026-03-27 Added Kicad Design files
2026-03-28 added 3d prints
    [screenBox_mixer.stl]
2026-04-10 Add Front Bezel Design and Gerber Files
2026-04-26 add top section
    [Top1.stl]
2026-04-27 Rev2 Radio board gerber and design files
2026-05-21 Rev2 Radio Board
    Rev2 Radio Board with support for ADE-1+ mixer
2026-06-26 Updated PCBS
2026-07-19 Updated Radio Gerbers and Design Files
2026-07-19 Added rear battery panel for holder box with 2x 18650 cells
    Added rear battery panel for holder box with 2x 18650 cells
